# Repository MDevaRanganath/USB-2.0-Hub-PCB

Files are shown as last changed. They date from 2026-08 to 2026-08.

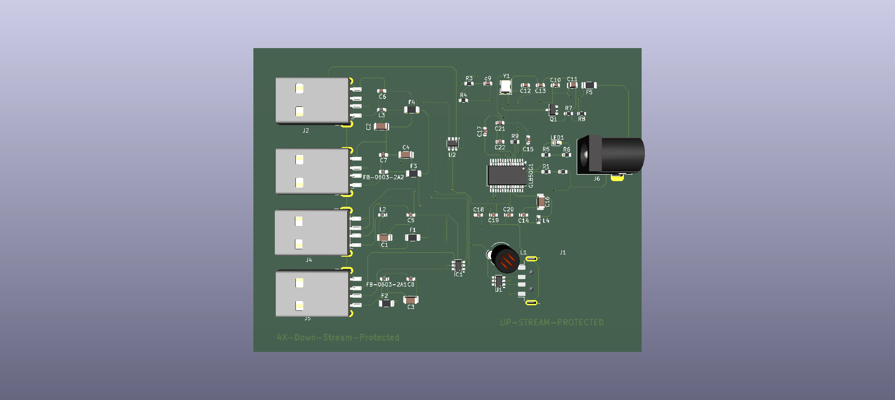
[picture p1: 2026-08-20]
3-D View/3D_Top_View.png

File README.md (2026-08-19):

# USB-2.0-Hub-PCB
PCB Design of 2 Layer USB 2.0 Hub in KiCad, comprising Schematic design, PCB Layout &amp; Routing, DRC Checking, 3D Visualization and Gerber Files

USB 2.0 Hub PCB Design

📌 Project Overview

This project presents the complete schematic and PCB design of a USB 2.0 Hub developed using KiCad.

The design includes the USB upstream interface, USB hub controller, downstream USB ports, ESD protection, power distribution, clock circuitry, reset circuitry, decoupling capacitors, and supporting passive components.

The project was developed following a complete PCB design workflow:

Schematic Design → Footprint Assignment → PCB Layout → Routing → 3D Verification → Gerber Generation → Bill of Materials (BOM).

The purpose of this project is to demonstrate practical skills in USB interface design, PCB schematic capture, component placement, PCB routing, design-rule verification, manufacturing preparation, and hardware documentation.

🎯 Project Objectives

The main objectives of this project are:
Design a functional USB 2.0 Hub PCB.
Create the complete electrical schematic.
Select appropriate electronic components and footprints.
Design the PCB layout using KiCad.
Route USB differential signal pairs appropriately.
Implement USB power distribution.
Include ESD protection for USB interfaces.
Implement reset and clock circuitry.
Add appropriate decoupling and bypass capacitors.
Perform Electrical Rules Check (ERC).
Perform Design Rules Check (DRC).
Verify the PCB using KiCad 3D Viewer.
Generate manufacturing-ready Gerber files.
Prepare a Bill of Materials (BOM).
Document the complete hardware design process.

🧩 System Architecture

The general architecture of the USB 2.0 Hub is:

                         USB HOST / COMPUTER
                                │
                                │
                         USB 2.0 UPSTREAM
                                │
                                ▼
                    ┌─────────────────────┐
                    │ Upstream Connector  │
                    └──────────┬──────────┘
                               │
                               ▼
                    ┌─────────────────────┐
                    │ ESD / USB Protection│
                    └──────────┬──────────┘
                               │
                               ▼
                    ┌─────────────────────┐
                    │   USB Hub Controller│
                    │         IC          │
                    └──────┬───┬───┬──────┘
                           │   │   │
                 ┌─────────┘   │   └─────────┐
                 ▼             ▼             ▼
          ┌───────────┐ ┌───────────┐ ┌───────────┐
          │ USB Port 1│ │ USB Port 2│ │ USB Port 3│
          └───────────┘ └───────────┘ └───────────┘
                                             │
                                      ┌───────────┐
                                      │ USB Port 4│
                                      └───────────┘

The exact architecture and number of ports depend on the implemented USB hub controller and final schematic.

🔌 USB Interfaces

The PCB contains:

Upstream USB Interface

The upstream interface connects the USB hub to a host computer or USB-enabled device.

It carries:

USB VBUS
USB D+
USB D−
GND
Downstream USB Interfaces

The downstream interfaces provide USB connectivity to external devices such as:

USB flash drives
USB keyboards
USB mice
USB development boards
Other USB 2.0-compatible peripherals

🛡️ Protection Circuitry

USB connectors are exposed to external devices and therefore require protection against electrostatic discharge and other transient events.

The design includes USB protection circuitry to improve interface robustness.

The protection section is intended to protect the USB signal and power lines while maintaining the required USB signal path.

⚡ Power Section

The power section distributes the required supply voltage to the USB hub controller and downstream USB interfaces.

The design includes appropriate:

Power input
VBUS connections
Ground connections
Decoupling capacitors
Power filtering/protection components

Care was taken to provide appropriate power paths and local bypass capacitors near the hub controller and other active components.

⏱️ Clock and Reset Circuitry

The USB hub controller requires appropriate clock and reset circuitry for reliable operation.

The design includes:

Clock/crystal circuitry
Load capacitors where required
Reset circuitry
Supporting passive components

These components are placed close to the relevant controller pins to reduce unnecessary routing and improve PCB implementation.

🖥️ Schematic Design

The complete schematic was developed using KiCad Schematic Editor.

The schematic includes:

USB upstream interface
USB downstream interfaces
USB hub controller
ESD protection
Power distribution
Clock circuit
Reset circuit
Decoupling capacitors
Pull-up/pull-down resistors
Supporting passive components
Schematic

A PDF version of the schematic is also provided in:

Schematic/Schematic_PDF.pdf
🟩 PCB Design

The PCB was designed using KiCad PCB Editor.

The PCB design process included:
Importing the schematic netlist into PCB Editor.
Assigning and verifying footprints.
Defining the board outline.
Placing components.
Routing signal traces.
Routing USB differential pairs.
Designing power connections.
Adding the ground plane.
Checking clearances.
Running DRC.
Performing 3D verification.
PCB Layout

📐 PCB Design Considerations

The following PCB design considerations were taken into account:
Component placement
Short and direct USB signal routing
USB differential pair routing
Ground return paths
Power distribution
Decoupling capacitor placement
Connector accessibility
PCB edge clearance
Track-to-track clearance
Thermal considerations
Silkscreen readability
Manufacturing constraints

🧪 Design Verification
The PCB design was verified using KiCad's electrical and physical design-checking tools.

ERC — Electrical Rules Check

ERC was used to identify electrical connectivity issues in the schematic.

Checks included:

Unconnected pins
Power connection issues
Incorrect electrical connections
Missing power drivers
Signal connectivity
DRC — Design Rules Check

DRC was performed on the PCB layout.

Checks included:

Track clearance
Pad clearance
Via clearance
Copper-to-edge clearance
Unconnected nets
Silkscreen violations
Hole and board-edge checks
Manufacturing-rule violations
DRC Result

Genuine design violations were reviewed and corrected before finalizing the PCB.

🧊 3D PCB Verification
KiCad 3D Viewer was used to inspect the completed PCB.

The 3D inspection helped verify:

Component placement
Connector orientation
Component height
PCB outline
Mechanical arrangement
Overall board appearance
3D Top View
3D Bottom / Angled View

🧾 Bill of Materials
A Bill of Materials is included in:

Manufacturing/BOM.csv

The BOM contains information such as:

Parameter	Description
Reference	Component reference designator
Component	Component type
Value	Component value
Footprint	Assigned PCB footprint
Quantity	Required quantity

🏭 Manufacturing Files
Manufacturing files are provided in the Gerber directory.

Gerber/
└── USB_2.0_Hub_Gerbers.zip
The Gerber package contains the fabrication data required for PCB manufacturing, including the relevant copper, solder mask, silkscreen, board outline, and drill information.
The Gerber package should be reviewed using a Gerber viewer before sending the design for fabrication.

🔄 PCB Design Workflow
Project Requirements
        ↓
Block Diagram
        ↓
Schematic Design
        ↓
Component Selection
        ↓
Footprint Assignment
        ↓
PCB Import
        ↓
Board Outline
        ↓
Component Placement
        ↓
USB Differential Pair Routing
        ↓
Power Routing
        ↓
Ground Plane
        ↓
ERC Verification
        ↓
DRC Verification
        ↓
3D PCB Inspection
        ↓
Gerber Generation
        ↓
Manufacturing Package

🛠️ Software and Tools

Design Software
KiCad
KiCad Schematic Editor
KiCad PCB Editor
KiCad 3D Viewer
KiCad Gerber Viewer
Version Control
Git
GitHub

💡 Technical Skills Demonstrated
This project demonstrates practical experience in:

PCB schematic design
PCB layout
Component selection
Footprint assignment
USB 2.0 interface design
USB differential pair routing
ESD protection
Power distribution
Decoupling
Ground-plane design
Component placement
PCB routing
ERC verification
DRC verification
3D PCB visualization
Gerber generation
BOM preparation
Hardware documentation
Git/GitHub version control

📂 Repository Structure
USB-2.0-Hub-PCB/
│
├── README.md
├── LICENSE
├── .gitignore
│
├── Schematic/
│   ├── USB_2.0_Hub.kicad_sch
│   └── Schematic_PDF.pdf
│
├── PCB/
│   ├── USB_2.0_Hub.kicad_pcb
│   └── PCB_3D_View.png
│
├── Gerber/
│   └── USB_2.0_Hub_Gerbers.zip
│
├── Manufacturing/
│   └── BOM.csv
│
├── Documentation/
│   └── Project_Report.pdf
│
└── Images/
    ├── 01_Block_Diagram.png
    ├── 02_Schematic.png
    ├── 03_PCB_Layout.png
    ├── 04_3D_Top_View.png
    ├── 05_3D_Bottom_View.png
    ├── 06_DRC_Result.png
    └── 07_Gerber_Viewer.png

🚀 Future Improvements
Possible future improvements include:

Fabrication of the PCB
PCB assembly and soldering
Hardware bring-up and testing
USB enumeration testing
USB data-transfer testing
Power-consumption measurements
Signal-integrity verification
ESD testing
Thermal testing
Validation of all downstream USB ports
Hardware debugging and performance optimization
📊 Project Status
Stage	Status
Requirements	✅ Completed
Schematic Design	✅ Completed
Component Selection	✅ Completed
Footprint Assignment	✅ Completed
PCB Layout	✅ Completed
PCB Routing	✅ Completed
ERC	✅ Completed
DRC	✅ Completed
3D Verification	✅ Completed
Gerber Generation	✅ Completed
PCB Fabrication	⏳ Future Work
Hardware Testing	⏳ Future Work

📜 License
This project is released under the CERN Open Hardware Licence – Permissive (CERN-OHL-P) v2.0.
See the LICENSE file for the complete license terms.

👨‍💻 Author

Mitte Devaranganath

B.Tech — Electronics and Communication Engineering

Areas of Interest
PCB Design
Digital Electronics
FPGA Design
Verilog/SystemVerilog
Hardware Design

⭐ Project Summary
This project demonstrates the complete development workflow of a USB 2.0 Hub PCB, from schematic capture and component selection through PCB layout, routing, verification, 3D inspection, and manufacturing-file generation.

The repository contains the design source files and supporting documentation required to understand, review, modify, and potentially manufacture the PCB.

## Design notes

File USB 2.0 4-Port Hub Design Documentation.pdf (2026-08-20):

# USB 2.0 4-Port Hub Using GL850G

## 1. Project Overview

This project presents the schematic and PCB design of a four-port USB 2.0 hub based on the Genesys Logic GL850G USB hub controller.

The purpose of the design is to provide multiple USB downstream ports from a single USB connection to a host computer such as a laptop or desktop PC.

The completed board contains:

One USB upstream interface for connection to a computer Four USB downstream Type-A ports
GL850G USB 2.0 hub controller
USB power protection
ESD protection
Over-current protection
External 5 V power input
Reset circuit
Status indication
12 MHz crystal oscillator
Decoupling and filtering components
PCB ground plane and routed USB differential signals

The GL850G supports USB 2.0 operation and can be configured for four downstream ports. Its upstream interface supports high-speed and full-speed USB operation, while its downstream interfaces support high-, full-, and low-speed USB devices.

# 2. Project Objectives

The main objectives of this project are:

Design a functional four-port USB 2.0 hub.
Use the GL850G as the central USB hub controller.
Provide an upstream USB interface for connection to a laptop or desktop computer. Provide four downstream USB Type-A ports.
Implement protection for USB power and data interfaces.
Provide external power input for self-powered operation.
Design the complete schematic using KiCad.
Design the PCB layout using KiCad PCB Editor.
Perform ERC and DRC verification.
Verify the physical PCB using KiCad 3D Viewer.
Generate the BOM and Gerber fabrication files.
Document the complete design for future modification and fabrication.

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
# 3. System Architecture

The overall system is organized around the GL850G USB hub controller.

HOST COMPUTER
Laptop / Desktop PC
USB UPSTREAM PORT
D+ / D- / VBUS
v
+-------------------+
| USB Protection |
+-------------------+
v
+-------------------+
| | GL850G | |
| | USB 2.0 HUB IC |
+-------------------+
D1 D2 D3 D4
v | v | v | v
USB USB USB USB
A | A | A | A
v | v | v | v
Device Device Device Device
| | ^
5 V POWER
+-------------------+
| External DC Input |
+-------------------+

The USB upstream port is the interface between the hub and the host computer. The four downstream ports are used to connect USB peripherals such as keyboards, mice, flash drives, USB adapters, and other compatible USB devices.

# 4. GL850G USB Hub Controller

The GL850G is the central component of the design.

It is a USB 2.0 hub controller designed for applications such as standalone USB hubs, PC motherboard hubs, notebook docking applications, and display/monitor hubs.

Important capabilities include:

USB 2.0 compliance
Four/three/two downstream-port configurations
High-speed and full-speed upstream operation
High-speed, full-speed, and low-speed downstream operation Integrated USB transceiver
Single Transaction Translator (TT)
Integrated 5 V to 3.3 V regulation
External 12 MHz crystal/clock support Power management functions
Over-current detection support
USB signal processing and routing

The GL850G uses an internal processor and USB control logic to manage communication between the host and downstream USB devices.

USB 2.0 high-speed operation uses a nominal data rate of 480 Mb/s.

# 5. Upstream USB Interface

The upstream interface is the most important addition required to connect the PCB to a laptop or desktop computer.

The upstream connector should be located at the edge of the PCB so that a USB cable can be physically connected.

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
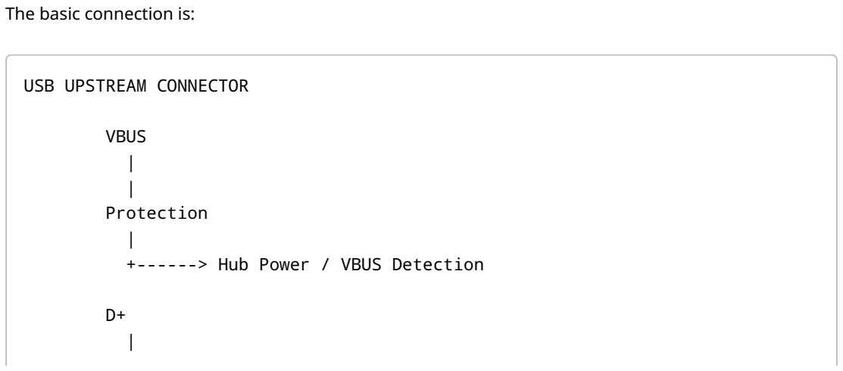
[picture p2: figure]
The basic connection is:; USB UPSTREAM CONNECTOR; VBUS | | Protection | +------> Hub Power / VBUS Detection

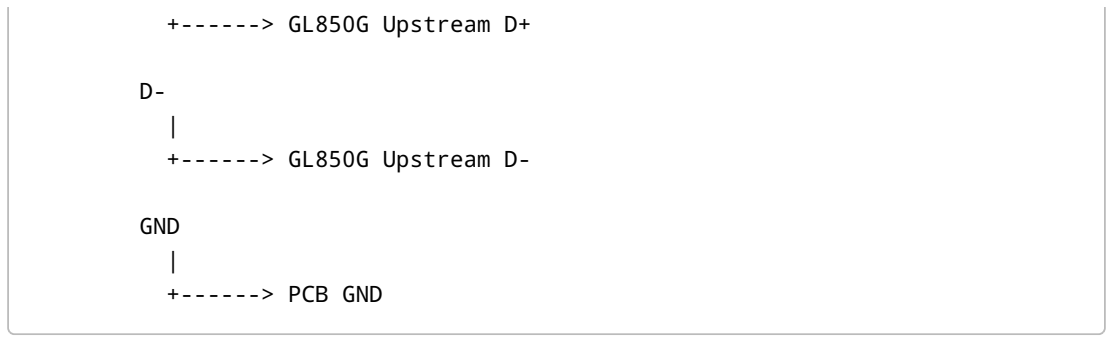
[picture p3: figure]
+------> GL850G Upstream D+; D- | +------> GL850G Upstream D-; GND | +------> PCB GND

The upstream USB connector provides the communication path between the computer and the GL850G.

Without this connector, the four downstream USB-A connectors cannot communicate with the computer.

# 6. Downstream USB Ports

The design contains four USB Type-A downstream ports.

They are designated as:

J2 → Downstream Port 1
J3 → Downstream Port 2
J4 → Downstream Port 3
J5 → Downstream Port 4

Each downstream port contains:

VBUS
D+
D-GND
USB protection
Power protection/current limiting where implemented

The general signal path is:

GL850G
+---- D+ / D- ---- Protection ---- USB-A |
+---- VBUS ------- Fuse/Switch --- USB-A |
+---- GND ------------------------- USB-A

•
•
•
•
•
•

The GL850G supports four downstream ports through its port configuration.

# 7. USB ESD Protection

Electrostatic discharge protection is included to protect the USB interface from external electrical transients.

ESD protection should be placed close to the corresponding USB connector.

The preferred signal path is:

USB Connector
v
ESD Protection
v
GL850G

Keeping the protection device close to the connector minimizes the length of the unprotected high-speed signal path.

The same principle should be applied to the upstream USB interface and downstream USB ports.

# 8. Over-Current Protection

Each USB downstream port requires appropriate power protection.

The design uses protection components in the VBUS paths of the downstream ports.

Conceptually:

5 V Supply
v
Protection / Current Limiting |
v
USB Port VBUS

The purpose is to reduce the possibility that a short circuit or excessive load on one USB port will damage the hub's power distribution circuitry.

# 9. External Power Input

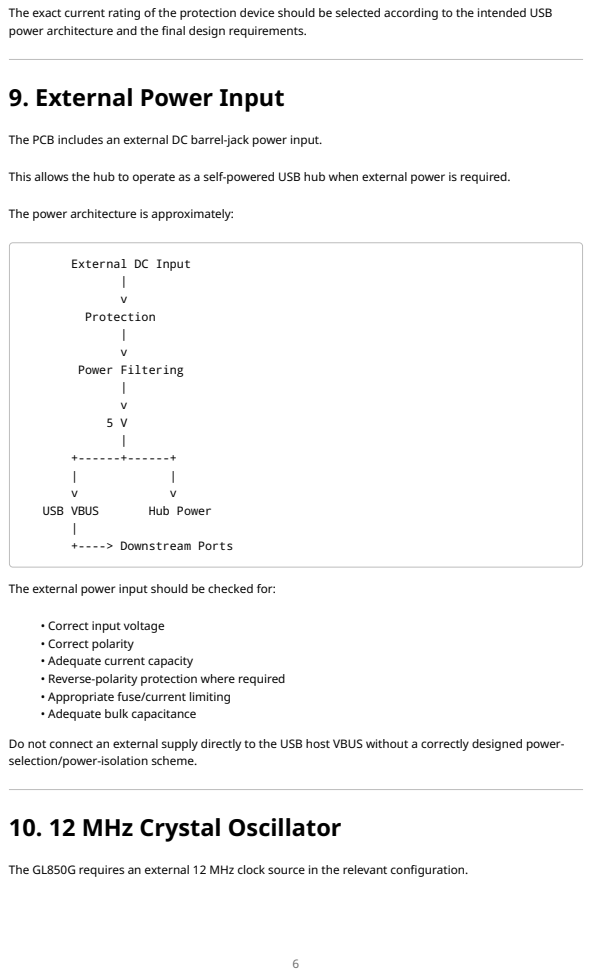
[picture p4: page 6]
| v Protection | v Power Filtering | v 5 V | +------+------+; USB VBUS; Hub Power; | +----> Downstream Ports

The exact current rating of the protection device should be selected according to the intended USB
power architecture and the final design requirements.

The PCB includes an external DC barrel-jack power input.

This allows the hub to operate as a self-powered USB hub when external power is required.

The power architecture is approximately:

External DC Input

The external power input should be checked for:

Correct input voltage
Correct polarity
Adequate current capacity
Reverse-polarity protection where required
Appropriate fuse/current limiting
Adequate bulk capacitance
Do not connect an external supply directly to the USB host VBUS without a correctly designed power-
selection/power-isolation scheme.
10. 12 MHz Crystal Oscillator

The GL850G requires an external 12 MHz clock source in the relevant configuration.

The design therefore includes:

12 MHz crystal
Crystal load capacitors
Short crystal connections

The clock section should be placed close to the GL850G.

Conceptually:

12 MHz Crystal
+-----------+
X1 --| | |-- X2
+-----------+
C1 | C2
GND | GND
v
GL850G

The GL850G documentation specifies support for an external 12 MHz crystal/clock source.

# 11. Reset Circuit

The design includes a reset circuit for the GL850G.

The reset circuit provides a defined startup condition for the controller.

A typical arrangement is:

VDD
R
+------ RESET
C
GND

The RC network creates a controlled reset interval during power-up.

•
•
•

The actual resistor and capacitor values should follow the selected GL850G package/datasheet requirements.

# 12. Status Indicators

LED indicators are included to provide visual information about the operating state of the board.

Possible indications include:

Power status
Hub activity/status
USB port status

A typical LED circuit is:

VDD
R
LED
GND

The LED current-limiting resistor must be selected according to the LED characteristics and controller output capability.

# 13. I²C / Configuration Interface

The design includes SCL and SDA-related circuitry with pull-up resistors.

The pull-up resistors provide the required logic-high bias for the open-drain style I²C signals.

Typical arrangement:

VDD
+---- R ---- SCL
+---- R ---- SDA

The final use of the configuration interface depends on the GL850G configuration and whether an external EEPROM or other configuration mechanism is required.

•
•
•

The GL850G documentation indicates that customized VID/PID and downstream-port configuration can be supported using external EEPROM configuration.

# 14. Power Distribution

The PCB contains a dedicated power-distribution section.

The major power paths are:

External 5 V
v
Protection
v
Filtered 5 V
+--------------------+
v | v
USB Downstream | Hub Power
VBUS | Circuit

Bulk capacitors are used to reduce supply fluctuations caused by changes in load.

Smaller ceramic capacitors are placed close to IC power pins for high-frequency decoupling.

# 15. Decoupling Capacitors

Decoupling capacitors are placed near the GL850G and other active components.

Their purpose is to provide local transient current and reduce high-frequency supply noise.

Typical arrangement:

VDD
+---- 100 nF ---- GND
+---- Bulk C ---- GND

The 100 nF capacitors should be placed physically close to the relevant IC power pins.

# 16. PCB Layout Design

The PCB was designed using KiCad PCB Editor.

The layout includes:

Four USB-A connectors
Upstream USB connector
GL850G controller
Power input connector
Protection components
Crystal oscillator
Reset circuitry
Status LEDs
Power filtering
Ground plane
USB differential-pair routing

The USB connectors are positioned around the board edges to make physical cable connection easier.

The GL850G is placed near the center of the board to reduce the distance between the controller and the USB interfaces.

# 17. USB Differential-Pair Routing

USB D+ and D− are high-speed differential signals.

Therefore, special attention should be given to:

Trace length
Differential-pair spacing
Impedance
Parallel routing
Ground reference
Avoidance of unnecessary vias
Avoidance of sharp routing discontinuities
Minimization of stubs

The USB 2.0 electrical compliance requirements include high-speed transmitter testing at 480 Mb/s, so the PCB layout should be treated as a high-speed design rather than ordinary low-frequency digital wiring.

The USB-IF maintains the USB 2.0 specification and electrical compliance documentation.

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
# 18. Ground Plane

A continuous ground plane should be maintained wherever practical.

The ground plane provides:

Lower impedance return paths
Improved signal integrity
Reduced EMI
Better power distribution
Improved thermal behavior

High-speed USB signal routing should maintain a suitable continuous reference plane.

# 19. PCB 3D Verification

KiCad 3D Viewer was used to inspect the physical arrangement of the PCB.

The 3D inspection verifies:

USB connector placement
Barrel jack placement
Component orientation
Component clearance
PCB dimensions
Mechanical positioning
Silkscreen placement

A component can appear in the 2D PCB Editor but not appear in the 3D Viewer if its footprint does not have a valid 3D model assigned.

Therefore, all important mechanical components should be checked for appropriate 3D models before fabrication.

# 20. Design Verification

The following verification steps should be completed before fabrication.

Schematic Verification

Verify all component references.
Verify component values.
Verify power connections.
Verify USB D+ and D− connections. Verify VBUS connections.
Verify GND connections.

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
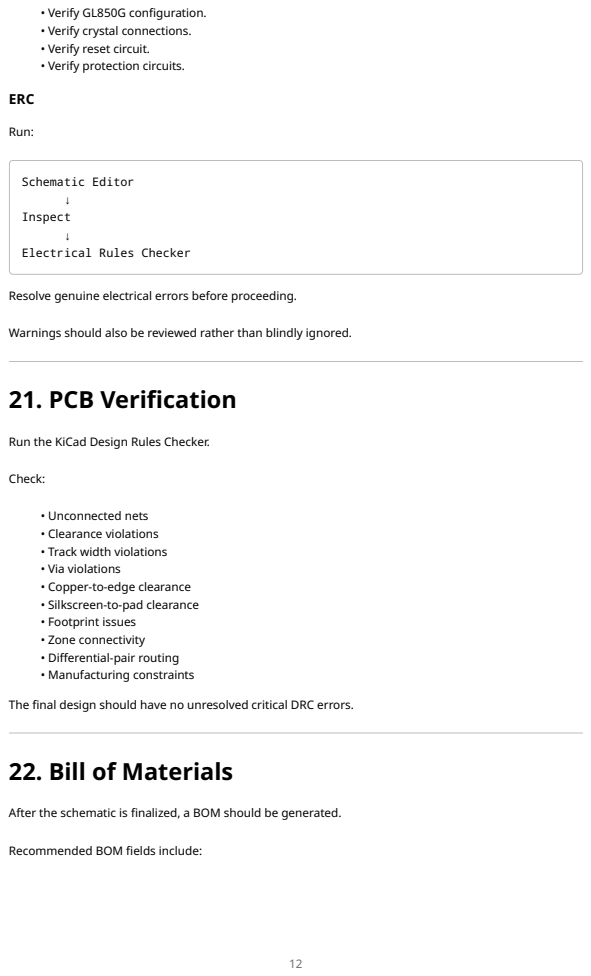
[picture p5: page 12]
Run:; Schematic Editor ↓ Inspect ↓; Check:

Verify GL850G configuration.
Verify crystal connections.
Verify reset circuit.
Verify protection circuits.
ERC

Electrical Rules Checker

Resolve genuine electrical errors before proceeding.

Warnings should also be reviewed rather than blindly ignored.
21. PCB Verification

Run the KiCad Design Rules Checker.

Unconnected nets
Clearance violations
Track width violations
Via violations
Copper-to-edge clearance
Silkscreen-to-pad clearance
Footprint issues
Zone connectivity
Differential-pair routing
Manufacturing constraints
The final design should have no unresolved critical DRC errors.
22. Bill of Materials

After the schematic is finalized, a BOM should be generated.

Recommended BOM fields include:

Field | Description
Reference | Component reference
Quantity | Number of components
Value | Electrical/component value
Description | Component description
Footprint | PCB footprint
Manufacturer | Component manufacturer
MPN | Manufacturer part number

The BOM should be stored in:

BOM/
├── USB_2.0_HUB_BOM.csv
└── USB_2.0_HUB_BOM.xlsx

The BOM should be regenerated whenever the component list changes.

# 23. Gerber Generation

After the PCB has passed DRC, Gerber files should be generated for fabrication.

Typical fabrication outputs include:

Copper layers
Solder mask
Silkscreen
Board outline
Drill files
Other fabrication layers required by the PCB manufacturer

The generated files should be compressed into:

USB_2.0_HUB_Gerbers.zip

and stored in:

Gerbers/

•
•
•
•
•
•

# 24. Recommended GitHub Repository Structure

The final repository should be organized as follows:

USB-2.0-Hub-PCB/
│
├── README.md
├── LICENSE
├── .gitignore
│
├── KiCad/
│ | ├── USB_2.0_HUB.kicad_pro
│ | ├── USB_2.0_HUB.kicad_sch
│ | ├── USB_2.0_HUB.kicad_pcb
│ | │
│ | ├── Libraries/
│ | │ | ├── USB_Hub.kicad_sym
│ | │ | └── USB_Hub.pretty/
│ | │
│ | └── 3D_Models/
│
├── BOM/
│ | ├── USB_2.0_HUB_BOM.csv
│ | └── USB_2.0_HUB_BOM.xlsx
│
├── Gerbers/
│ └── USB_2.0_HUB_Gerbers.zip
│
├── Images/
│ | ├── Schematic.png
│ | ├── PCB_Layout.png
│ | └── PCB_3D_View.png
│
└── Documentation/
└── USB_2.0_HUB_Design.pdf

# 25. Project Design Flow

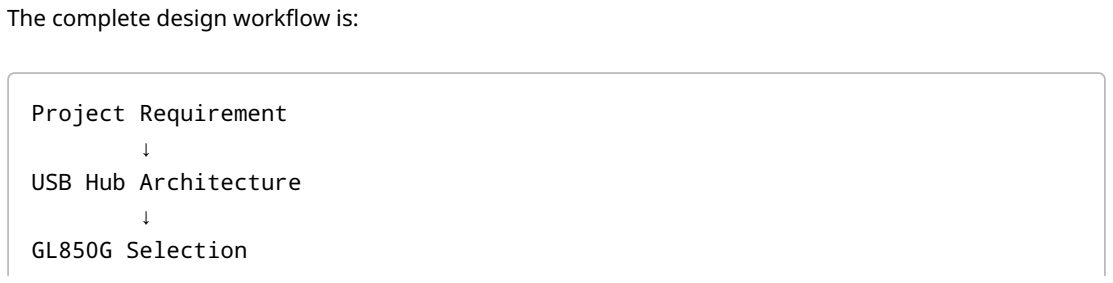
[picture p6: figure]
The complete design workflow is:; Project Requirement ↓ USB Hub Architecture ↓ GL850G Selection

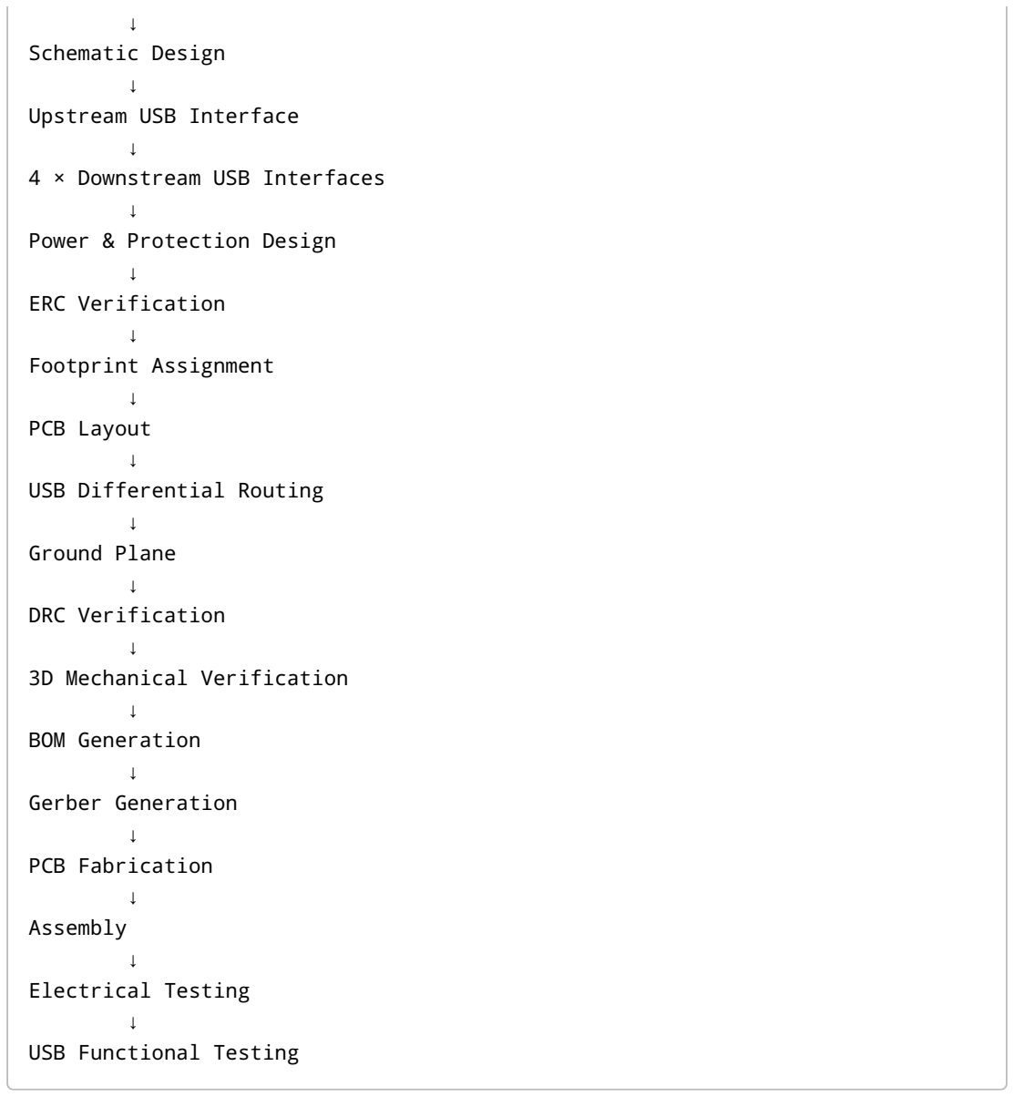
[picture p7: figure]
↓ Schematic Design ↓ Upstream USB Interface ↓ 4 × Downstream USB Interfaces ↓ Power & Protection Design ↓ ERC Verification ↓ Footprint Assignment ↓ PCB Layout ↓ USB Differential Routing ↓ Ground Plane ↓ DRC Verification ↓ 3D Mechanical Verification ↓ BOM Generation ↓ Gerber Generation ↓ PCB Fabrication ↓; Assembly; ↓ Electrical Testing ↓ USB Functional Testing

# 26. Testing Plan

After fabrication and assembly, the following tests should be performed.

Power Test

Before connecting the board to a computer:

Inspect the PCB for solder bridges.
Check resistance between power and ground. Apply the external supply with current limiting. Measure the 5 V rail.
Verify the regulated 3.3 V rail.

1.
2.
3.
4.
5.

Check for excessive current consumption. USB Host Test

Connect the upstream USB connector to a computer.

Check whether the operating system detects the USB hub.

The expected structure is:

Computer
v
USB Hub
+---- USB Device 1
+---- USB Device 2
+---- USB Device 3
+---- USB Device 4

Downstream Test

Test each port individually using known-good USB devices.

Test:

USB flash drive
Keyboard
Mouse
USB-to-serial adapter
Other USB 2.0 compatible devices

Each downstream port should be tested separately.

# 27. Important Design Considerations

This project should be treated as a USB high-speed design.

Before fabrication, verify the final GL850G package, pinout, power requirements, reset configuration, crystal network, USB protection, and power architecture against the exact manufacturer documentation for the device/package being used.

This is particularly important because GL850G documentation exists for different package configurations, and some features differ between package variants.

USB-IF publishes the USB 2.0 base specification and electrical compliance documentation that should be consulted when validating a production-oriented implementation.

6.

•
•
•
•
•

# 28. Current Project Status

Completed / Designed

USB 2.0 hub architecture
GL850G hub controller section Four downstream USB ports
Power input section
Protection circuitry
Reset circuit
Crystal oscillator section Status indication
PCB layout
PCB routing
KiCad 3D visualization
Finalization Items

Before calling the project fabrication-ready:

Verify the upstream USB connector and its complete protection/power connections. Verify the exact GL850G package and pin assignment.
Complete ERC review.
Complete DRC with no critical violations.
Verify all 3D models.
Verify USB D+/D− routing.
Verify power-rail isolation and current protection. Generate the final BOM.
Generate final Gerbers.
Perform a final schematic-to-PCB consistency check.

# 29. Conclusion

The project demonstrates the complete design process of a four-port USB 2.0 hub, from schematic development through PCB layout and manufacturing preparation.

The GL850G provides the central USB hub functionality, while the PCB integrates the upstream computer interface, four downstream USB ports, power distribution, protection circuits, clock generation, reset circuitry, and status indication.

The final KiCad project files, BOM, Gerber package, PCB images, and design documentation should be maintained together in the GitHub repository so that the design can be reviewed, modified, reproduced, and fabricated in the future.

The project provides practical experience in:

USB 2.0 hardware design

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
High-speed differential routing Power distribution
ESD and over-current protection KiCad schematic design
PCB layout
ERC/DRC verification
3D mechanical verification BOM preparation
Gerber generation
Hardware documentation
GitHub-based hardware project management

## References

Genesys Logic GL850G USB 2.0 Hub Controller Datasheet.
USB Implementers Forum – USB 2.0 Specification and Document Library. USB Implementers Forum – USB 2.0 Electrical Compliance Specification.

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
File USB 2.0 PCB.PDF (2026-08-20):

# Printout

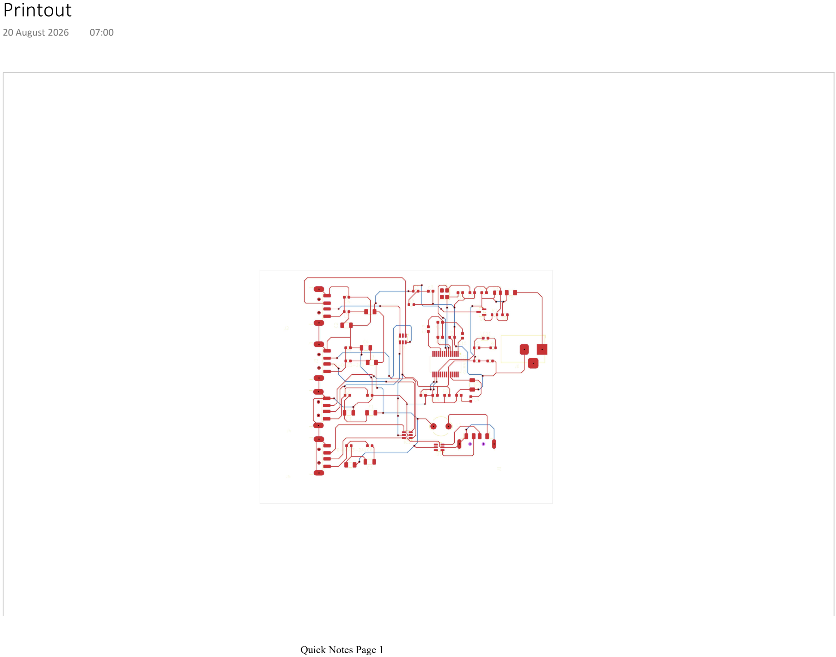
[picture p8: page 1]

### 20 August 2026 07:00

Quick Notes Page 1

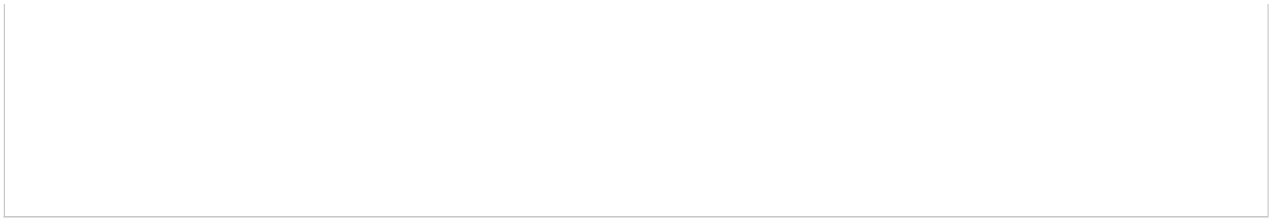
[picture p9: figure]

Quick Notes Page 2

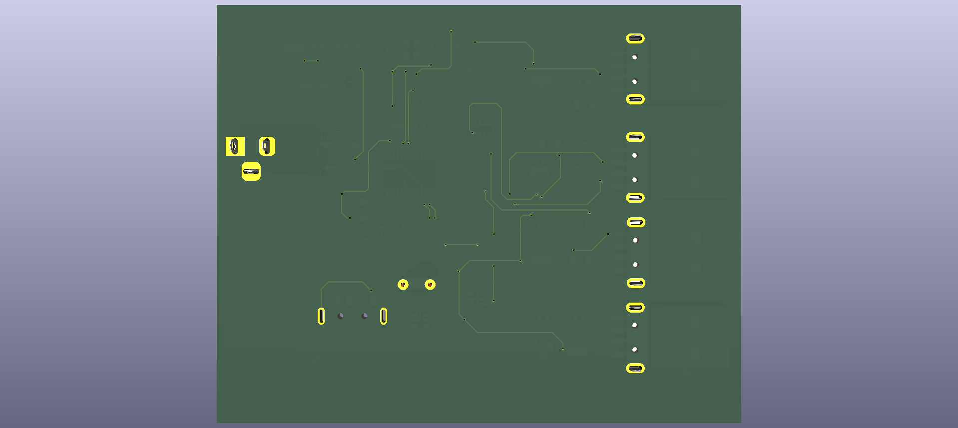
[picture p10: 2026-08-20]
3-D View/3D_Bottom_View.png

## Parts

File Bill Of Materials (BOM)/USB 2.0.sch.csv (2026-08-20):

Id | Designator | Footprint | Quantity | Designation | Supplier and ref
1 | C1, C2 | C_1206_3216Metric | 2 | 100 µF
2 | C3, C4 | C_1206_3216Metric | 2 | 100 µF-10V
3 | C5, C6 | C_0603_1608Metric | 2 | 0.1 µF
4 | C7, C8 | C_0603_1608Metric | 2 | 0.1 µF-10V
5 | c9 | C_0603_1608Metric | 1 | 0.1uF
6 | C10 | C_0603_1608Metric | 1 | 100nF
7 | C11 | C_0805_2012Metric | 1 | 10 µF
8 | C12, C13 | C_0603_1608Metric | 2 | 33pF
9 | C14, C15, C17, C18, C20, C22 | C_0603_1608Metric | 6 | 0.1µF
10 | C16 | C_1206_3216Metric_Pad1.33x1.80mm_HandSolder | 1 | 10µF
11 | C19, C21 | C_0603_1608Metric | 2 | 1µF
12 | F1, F2, F3, F4 | Fuse_1206_3216Metric | 4 | 500 mA / 6 V PTC
13 | F5 | Fuse_1206_3216Metric | 1 | Fuse
14 | FB-0603-2A1 | L_0603_1608Metric | 1 | L1
15 | FB-0603-2A2 | L_0603_1608Metric | 1 | L2
16 | GL850G1 | SSOP-28_5.3x10.2mm_P0.65mm | 1 | GL850G
17 | IC1, U1, U2 | SOT-23-6 | 3 | SRV05-4
18 | J1 | USB_A_Molex_48037-2200_Horizontal | 1 | USB_A
19 | J2, J3, J4, J5 | USB_A_CNCTech_1001-011-01101_Horizontal | 4 | USB_A
20 | J6 | BarrelJack_Horizontal | 1 | Barrel_Jack
21 | L1 | LairdTech_28C0236-0JW-10 | 1 | FB-0603-2A
22 | L2, L3 | L_0603_1608Metric | 2 | FB-0603-2A
23 | L4 | L_0603_1608Metric | 1 | 600Ω @100MHz
24 | LED1 | LED_0603_1608Metric | 1 | RED
25 | Q1 | SOT-23 | 1 | 2.5 A, 30 V, ~105 mΩ
26 | R1, R3 | R_0603_1608Metric | 2 | 10K
27 | R2 | R_0603_1608Metric | 1 | 20K
28 | R4 | R_0603_1608Metric | 1 | 47K
29 | R5 | R_0603_1608Metric | 1 | R11
30 | R6 | R_0603_1608Metric | 1 | 470R
31 | R7 | R_0603_1608Metric | 1 | 4.7k
32 | R8 | R_0603_1608Metric | 1 | 470k
33 | R9 | R_0603_1608Metric | 1 | 680Ω
34 | Y1 | Crystal_SMD_3225-4Pin_3.2x2.5mm | 1 | 12MHz

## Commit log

2026-08-19 Enhance README with comprehensive project details
    Expanded the README to provide detailed project overview, objectives, system architecture, design considerations, verification processes, and future improvements for the USB 2.0 Hub PCB design.
2026-08-20 Create KICAD
2026-08-20 Update and rename KICAD to LICENSE
2026-08-20 Remove USB 2.0.sch.kicad_pcb path from KiCad
